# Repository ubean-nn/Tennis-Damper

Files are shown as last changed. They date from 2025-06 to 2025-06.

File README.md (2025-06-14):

# 🎾 3D‑Printed Tennis Racket Damper – Rapid Prototype

<p align="center">
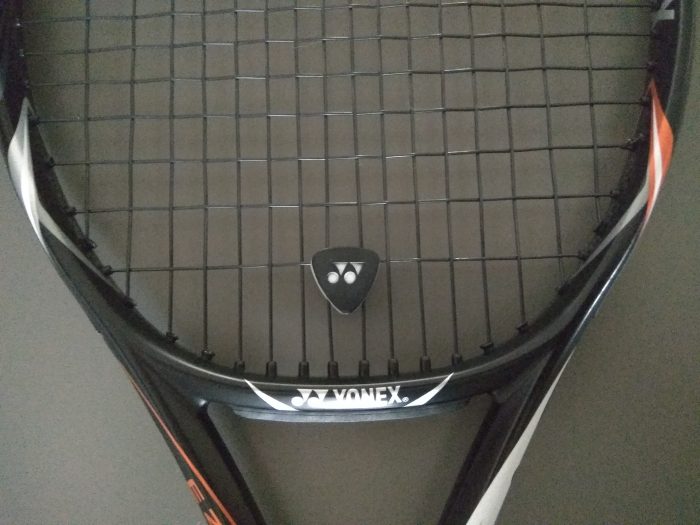
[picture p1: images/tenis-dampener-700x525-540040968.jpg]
  
</p>

## Project Overview
I decided to prototype for 24-hours to create a vibration damper for a tennis racket, aiming to replicate the performance of commercial silicone dampers. The goal: design and manufacture a functional damper, that's cheaper than a traditional one, using a 3D-printer.

<p align="center"></strong> What is a damper though and why do people use them????

A tennis racket damper is a small object, that come in many different shapes and designs, players use on thier rackets that is made from soft flexible materials like silicone or rubber. When you hit a tennis ball, the strings and frame of the racket vibrate. Some of these vibrations travel down the handle and into the player’s hand and arm. **A damper helps absorb or lessen the “ping” and sharp vibrations from the strings**. Many players find this far more comfortable to play with, however its completely up to personal preference wether it matters or not. Me personally, find using a damper much more comfortable but it is not vitale to me.

## My Design Process
The design I decided to follow for my testing trials was based off of a simple HEAD damper I have, which is pictured below:

<p align="center">
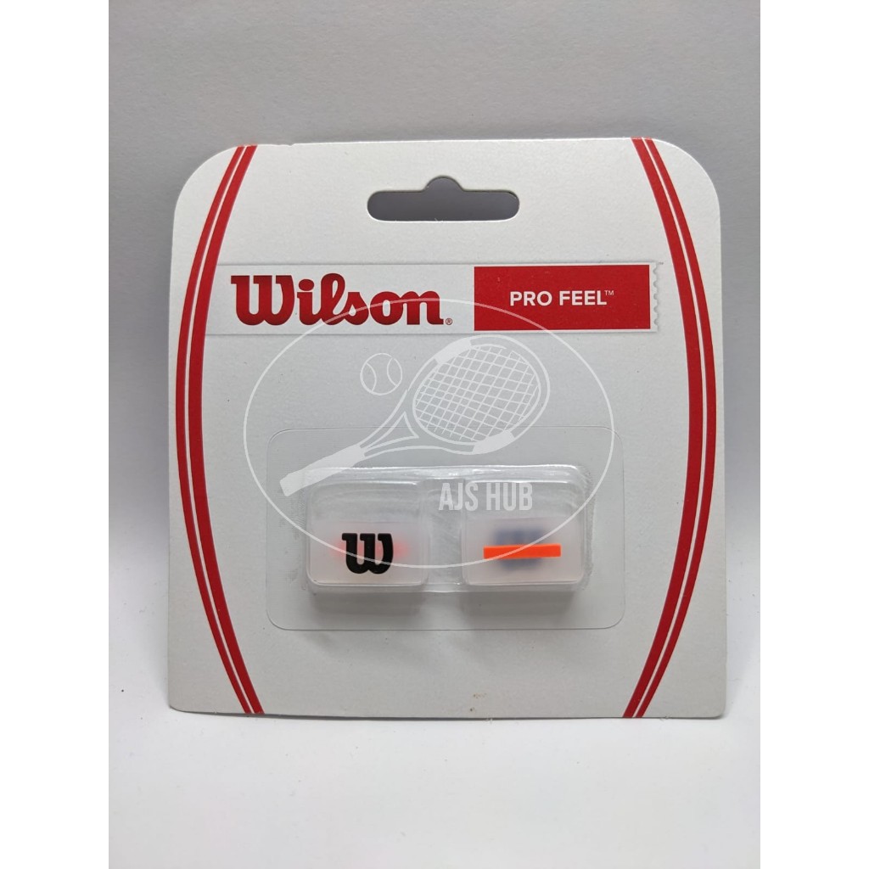
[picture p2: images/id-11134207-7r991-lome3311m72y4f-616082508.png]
  
</p>

Luckily this was easy to 3d model and helped me with my self-assigned time constraints. Later, you’ll see that I developed a modular, three-piece system—basically three of these head dampers—modeled after an [ADV tennis dampener](https://www.amazon.com/ADV-Tennis-Vibration-Absorbers-Technology/dp/B079R5PFKF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) design I discovered online. I read that the [ADV dampener](https://www.amazon.com/ADV-Tennis-Vibration-Absorbers-Technology/dp/B079R5PFKF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), with its design spanning multiple strings, was intended to aggressively dampen racket vibrations. That’s where I drew inspiration for my three-piece system.

<p align="center">
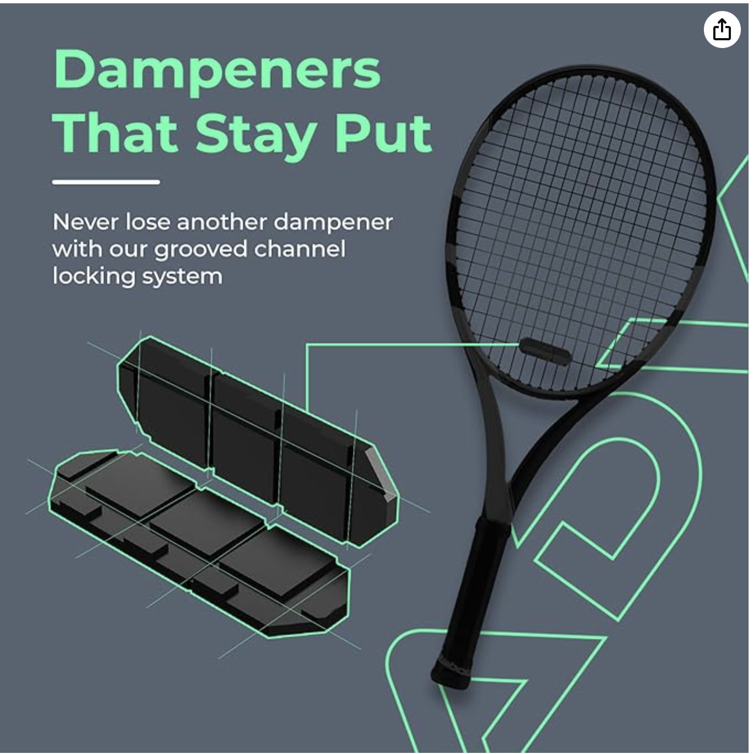
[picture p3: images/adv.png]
  
</p>

## Material Testing & Printing Parameters
The first challenge was working with the TPU filament, which behaves differently based on print temperature and infill settings. So I ran trials changing one variable at a time such as the printing temperature, infill percentage, and even infill pattern. Although the manufacturer-recommended printing temperature was 200 °C, I encountered persistent jams. By increasing the temperature to 210 °C, the printing process became stable and reliable, allowing for further experimentation. As for infill percentages, I tested with a range from 70 % down to 0 % and observed that lowering the infill increased malluability.

<p align="center">
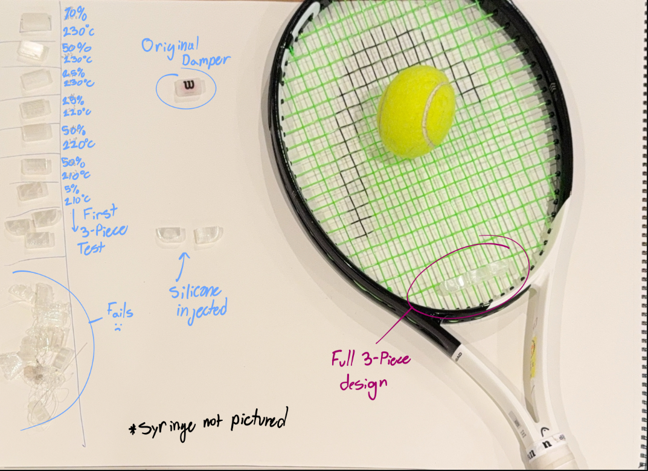
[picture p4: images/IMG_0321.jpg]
  
</p>

As you can see in the image above, I experimented with various infill percentages, printing temperatures, and infill patterns. In my initial iterations, I tried a “gyroid” infill pattern, which looks like this: 

<p align="center">
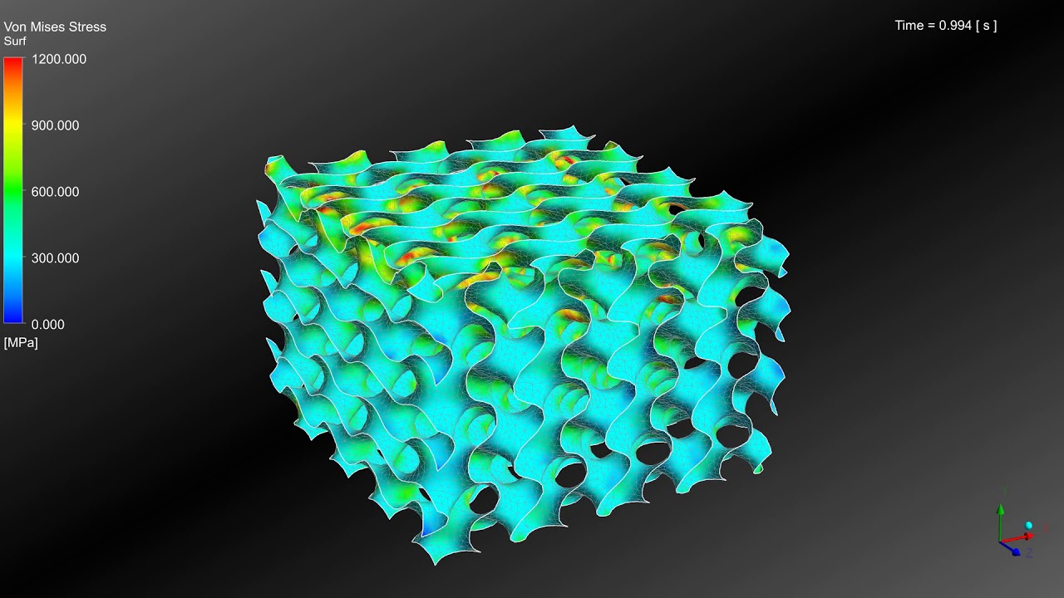
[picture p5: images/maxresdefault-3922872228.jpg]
  
</p>

Later, I switched to a TPMS-D (Triply Periodic Minimal Surface) cell pattern, which was new to me and turned out to be much better suited for my future plans of injecting silicone into the damper(No picture avalible but it looks simalar to the gyroid design).

Overall, I found that the higher the printing temperature, the firmer the resulting material became. Conversely, using a lower infill percentage—regardless of the temperature—produced a softer and more malleable print. This meant to acquire the closest similarity to the properties of general silicone dampers, like my HEAD one, I would need a relatively low infill percentage and print at a lower temperature of around 210 degrees celcius.

## Silicone Injection Process
As mentioned earlier, my experiments with different TPU variables showed that a lower infill percentage produced a more flexible print, making the damper feel much closer to the original silicone version I was using. While achieving this flexibility was one of my goals, the lack of internal material meant there was little to no actual vibration damping happening. Knowing this, I explored solutions for filling the damper’s interior with another material. While searching my garage, I found some silicone and decided to try a silicone-injected approach. Since the nozzle on the original silicone bottle was far too large for these small parts, I first transferred the silicone into a syringe to inject it into the partial 3D print. However, even the syringe tip was a bit too big for the small channels in the print. To solve this, I designed and 3D-printed a custom nozzle that fit onto the syringe, making the injection size much smaller and allowing for more precise work at the scale of the 3D print. 

<p align="center">
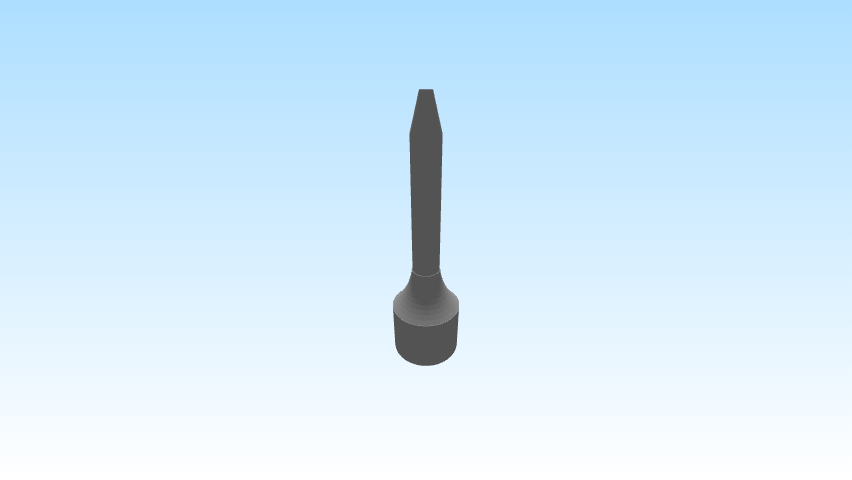
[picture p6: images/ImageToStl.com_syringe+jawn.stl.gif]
  
</p>

Pausing the print for manual injection required careful timing and precision. While several prints failed due to poor layer adhesion or contamination, a few did work, producing a silicone-filled structure that felt promising during initial tests(bouncing a tennis ball on the racket and feeling for vibrations and audible 'pinging' noises).

## Final Design: Modular Three-Wing Damper
The finalized design comprises three separate TPU wings (0 % infill, printed at 210 °C) with silicone injected into each cavity. This modular layout increases coverage across the strings, theoretically enhancing damping capability. Preliminary play tests confirmed a subtle yet noticeable difference in vibration and acoustics—the racket produced less “ping” and the feel during impact was more muted compared to playing without any damper.

<p align="center">
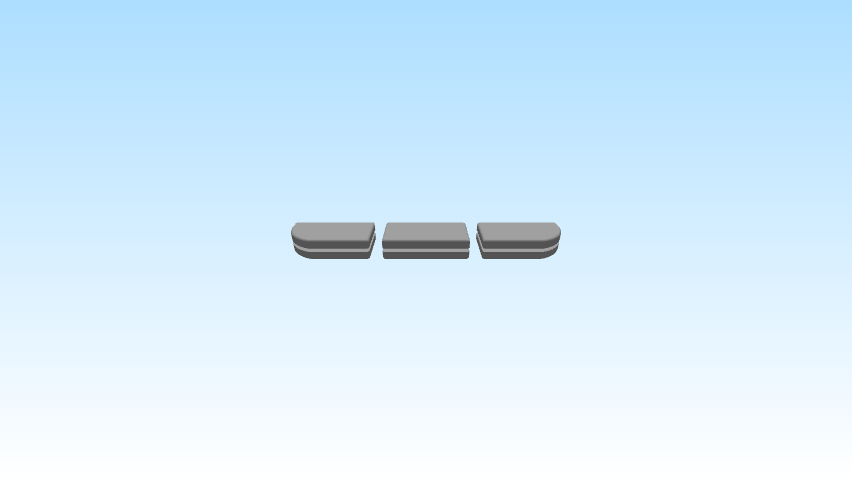
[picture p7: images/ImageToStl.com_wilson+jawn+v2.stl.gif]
  
</p>

## Cost Breakdown & Performance
Commercial silicone dampers range from $3.99 to $6.00 in retail outlets . In contrast, my wired calculations show my prototype costs approximately $0.10 per unit to produce. As for performance metrics, this remains qualitative; no specialized equipment was used. However, from personal testing, the silicone-injected prototype reduced vibration in a perceivable way, at least compared to using no damper.

# Future Directions & Improvements
This proof-of-concept reveals several clear paths for improvement:

**Refined injection process:** Develop a more precise method (potentially automated) for introducing silicone cleanly and consistently without layer failure.

**Design optimization:** Compare the current modular model with a single-piece design to evaluate differences in dampening effectiveness.

**Materials exploration:** Research additional filaments and elastomers for better integration or performance.

**Iterative testing:** Continue refining over time, particularly as dampers are lost during play—availability and ease of reprinting are key strengths of this approach.

Conclusion
My rapid protoyping shows that combining flexible TPU and injected silicone can create a functional and ultra-low-cost vibration damper. Despite several failed prints during the process—a natural part of rapid prototyping—the final three-piece damper, manufactured in under 24 hours and costing roughly ten cents, delivered a noticeable reduction in vibration. With further development, this could evolve into a customizable and cost-effective alternative to standard commercial dampers.

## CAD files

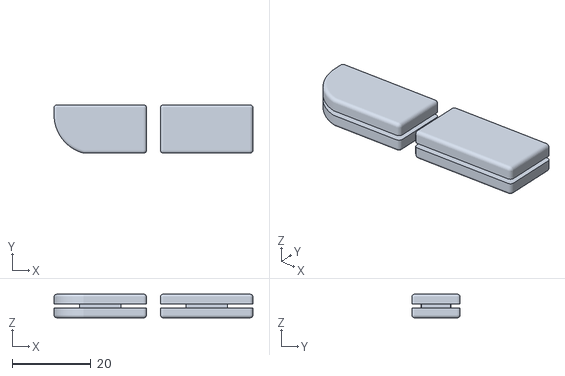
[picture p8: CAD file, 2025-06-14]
stl-model-files/wilson jawn v3.stl
50.5 x 12.2 x 6.00

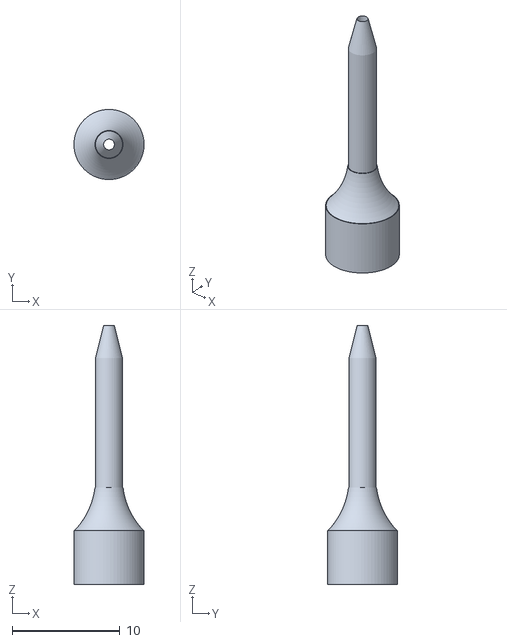
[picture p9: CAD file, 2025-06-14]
stl-model-files/syringe jawn.stl
6.50 x 6.50 x 24.0

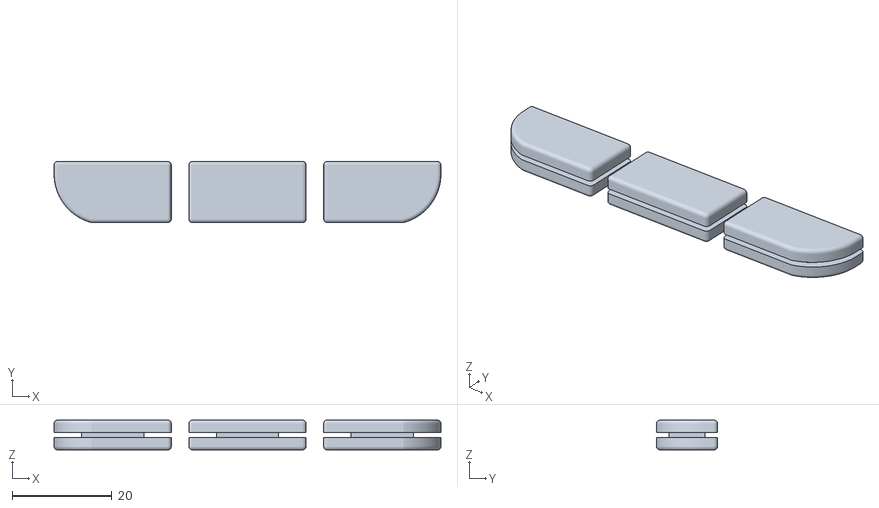
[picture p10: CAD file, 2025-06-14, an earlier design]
stl-model-files/wilson jawn v2.stl
77.5 x 12.2 x 6.00

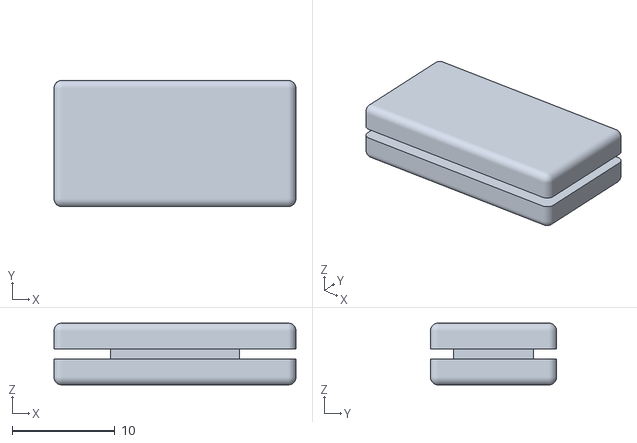
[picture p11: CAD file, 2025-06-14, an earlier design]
stl-model-files/wilson jawn v1.stl
23.5 x 12.2 x 6.00

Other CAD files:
stl-model-files/wilson jawn v1.f3d
